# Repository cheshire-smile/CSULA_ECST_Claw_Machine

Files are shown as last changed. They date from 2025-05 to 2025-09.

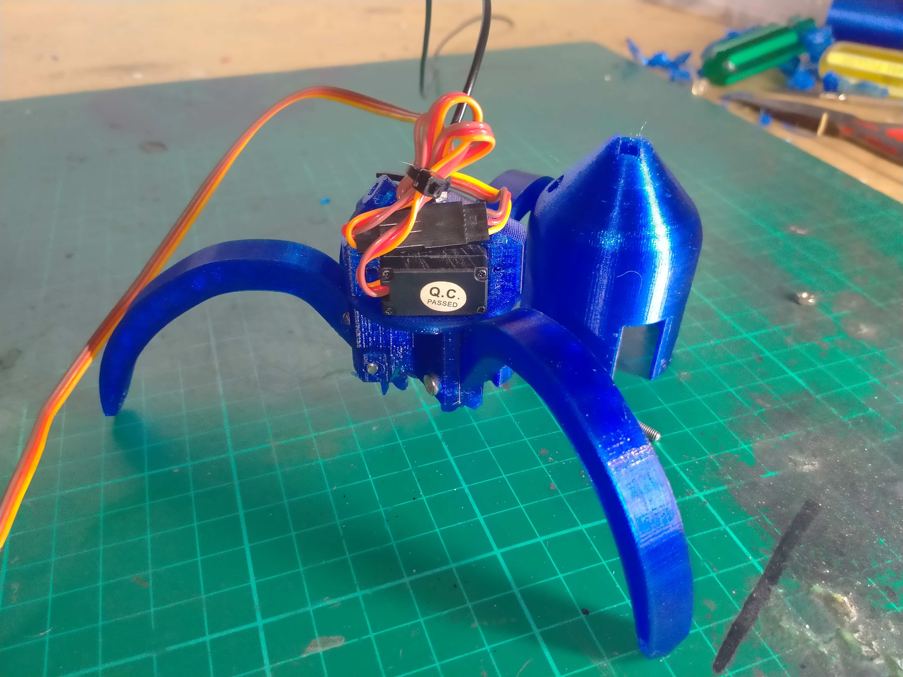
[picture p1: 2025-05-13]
Design_Files/Claw_Machine_V5/7_3 Cube Parts/Sub_Assemblys/Mini Servo operated Claw Machine Claw Grabber - 4826548/images/IMG20210413201654.jpeg

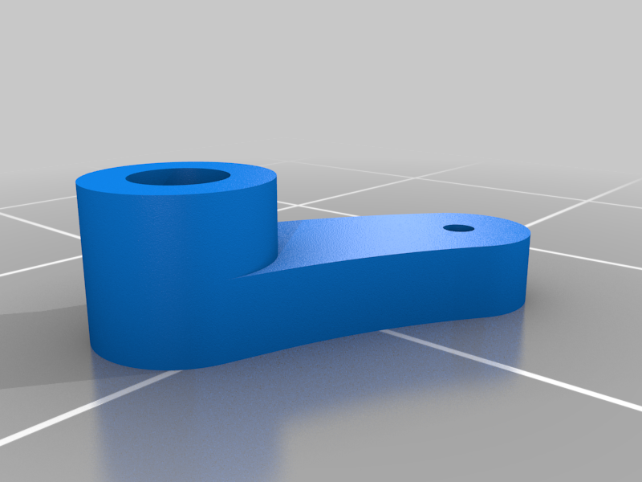
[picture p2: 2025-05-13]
Design_Files/Claw_Machine_V5/7_3 Cube Parts/Sub_Assemblys/Mini Servo operated Claw Machine Claw Grabber - 4826548/images/Servo_Linkage_Part_2.png

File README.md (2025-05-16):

This was a project created at California State University
as part of the SMART internship in Summer of 2024

It is a claw machine designed and built.
The design files contain the solidworks files used to CNC, laster cut, and 3D print the necessary parts

The code is designed for an STM32 NUCLEO-F030R8 board

CSULA ECST
https://www.calstatela.edu/ecst

information about the SMART internship:
https://www.smartscholarship.org/smart/en

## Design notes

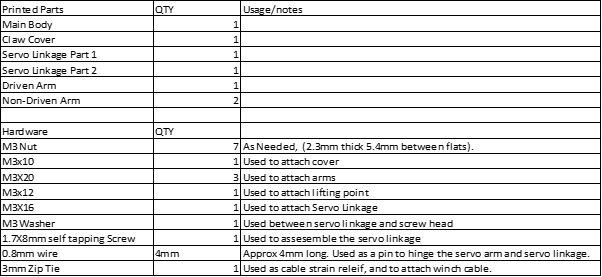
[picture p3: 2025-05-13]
Design_Files/Claw_Machine_V5/7_3 Cube Parts/Sub_Assemblys/Mini Servo operated Claw Machine Claw Grabber - 4826548/images/Hardware.png

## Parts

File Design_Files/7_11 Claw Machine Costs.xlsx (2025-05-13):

Received? | Item/Material | Amount Needed | Price | Total Cost | Notes | Link
FALSE |  |  |  | $440.57
FALSE | 24in Aluminum | 12 | $3.98 | $47.76 | Includes 2 for the Gantry that has NOT been added to Solidworks
FALSE | 36in Aluminum | 5 | $5.72 | $28.60
FALSE | 30in Aluminum | 2 | $4.85 | $9.70
TRUE | 25.5 x 22.35in Acyrlic (24 X 36 order) | 1 | $37.35 | $37.35 | For the front | https://www.mcmaster.com/8560K261/
TRUE | 25.5 x 22.44in Acrylic(24 X 36 order) | 2 | $37.35 | $74.70 | For the 2 sides | https://www.mcmaster.com/8560K261/
TRUE | Joystick | 1 | $12.18 | $12.18 |  | https://www.amazon.com/Machine-Fighting-Joystick-Compact-Lifespan/dp/B0C3ZKVRTC
TRUE | Button | 1 | $12.99 | $12.99 | For Drop, not sure if one in link works | https://www.amazon.com/EG-STARTS-American-Standard-Switchable/dp/B07GBSJX2H?rnid=386453011
TRUE | Idler Timing Pulley w/Bearing 20T | 1 | $9.99 | $9.99 | For CoreXY configuration Kit comes with 10 Pulleys | https://www.amazon.com/gp/product/B07J4JC2N7/ref=ox_sc_act_title_1?smid=AMFXXBA3KGILA&psc=1
TRUE | V Slot Gantry Plate | 2 | $7.67 | $15.34 | For X Axis motion | https://www.amazon.com/gp/product/B0986PYTNJ/ref=ox_sc_act_title_2?smid=A2DGLVBBDAJTOF&th=1
TRUE | GT2 Timing Belt and Pulley Kit | 1 | $14.99 | $14.99 | For X and Y motion, only comes with one belt | https://www.amazon.com/gp/product/B07XG9JN5B/ref=ox_sc_act_title_3?smid=AK64CGABQOWCO&th=1
TRUE | 2020 Profile X-axis Synchronous Belt Tensioner | 2 | $13.99 | $27.98 | For tensioning x and y axis belts | https://www.amazon.com/gp/product/B07XL41QNH/ref=ox_sc_act_title_4?smid=A3C0HXP4AGBIOG&th=1
TRUE | V Wheel with Plate and 6mm Belt Buckle | 1 | $18.99 | $18.99 | For antry payload (claw) | https://www.amazon.com/gp/product/B08M3JKKZY/ref=ox_sc_act_title_5?smid=A3C0HXP4AGBIOG&th=1
TRUE | Aluminum Extrusion Profiles Corner Brackets with T-Nuts | 1 | $19.97 | $19.97 | Kit Comes with 20 | https://www.amazon.com/gp/product/B0855V2JV3/ref=ox_sc_act_title_1?smid=A4HTD69KS4TBJ&th=1
TRUE | 2020 L Brackets | 1 | $11.97 | $11.97 | L Bracket for cross members | https://www.amazon.com/gp/product/B09BC1D3H2/ref=ox_sc_act_title_2?smid=A4HTD69KS4TBJ&psc=1
TRUE | GT2 Belt 2mm Pitch 6mm Wide | 1 | $9.99 | $9.99 | For Y axis | https://www.amazon.com/HICTOP-Printer-Creality-Printers-16-5ft/dp/B00YMM6IQW
TRUE | Stepper Motor | 2 | $21.95 | $43.90 | Motion | https://www.pololu.com/product/2267
FALSE | Stepper Motor Mounting Plate | 1 | $9.79 | $9.79 | Comes with 2 | https://www.amazon.com/HEVSTIL-Mounting-Aluminum-Suitable-Stepper/dp/B09XCD5F2Y
TRUE | Stepper Driver Board | 2 | $7.95 | $15.90 | Motion | https://www.pololu.com/product/2134
TRUE | Limit Switches | 1 | $5.99 | $5.99 | For Homing and safety | https://www.amazon.com/HiLetgo-KW12-3-Roller-Switch-Normally/dp/B07X142VGC
TRUE | STM32 Nucleo F401RE | 1 |  | $0.00 | Already on hand
TRUE | 5V Power Supply | 1 | $12.49 | $12.49 | 5v power supply | https://www.amazon.com/MEAN-WELL-RS-15-5-Supply-Single/dp/B005T6UJBU
 |  |  |  | $0.00
 |  |  |  | $0.00
 |  |  |  | $0.00
 |  |  |  | $0.00
 |  |  |  | $0.00
 |  |  |  | $0.00
 |  |  |  | $0.00
 |  |  |  | $0.00
 |  |  |  | $0.00
 |  |  |  | $0.00
 |  |  |  | $0.00

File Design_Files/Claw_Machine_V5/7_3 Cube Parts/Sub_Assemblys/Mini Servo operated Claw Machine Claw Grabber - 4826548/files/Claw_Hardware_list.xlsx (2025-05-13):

Printed Parts | QTY | Usage/notes
Main Body | 1
Claw Cover | 1
Servo Linkage Part 1 | 1
Servo Linkage Part 2 | 1
Driven Arm | 1
Non-Driven Arm | 2
Hardware | QTY
M3 Nut | 7 | As Needed, (2.3mm thick 5.4mm between flats).
M3x10 | 1 | Used to attach cover
M3X20 | 3 | Used to attach arms
M3x12 | 1 | Used to attach lifting point
M3X16 | 1 | Used to attach Servo Linkage
M3 Washer | 1 | Used between servo linkage and screw head
1.7X8mm self tapping Screw | 1 | Used to assesemble the servo linkage
0.8mm wire | 4mm | Approx 4mm long. Used as a pin to hinge the servo arm and servo linkage.
3mm Zip Tie | 1 | Used as cable strain releif, and to attach winch cable.

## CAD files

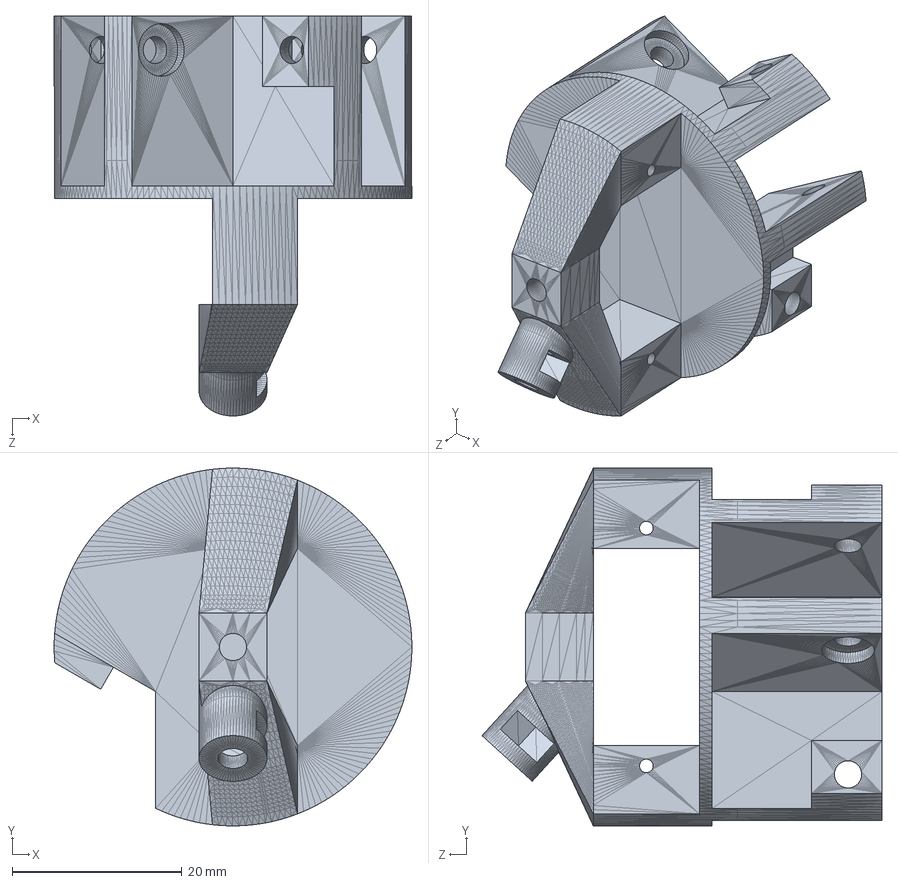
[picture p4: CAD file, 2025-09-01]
Design_Files/Claw_Machine_V5/7_3 Cube Parts/Sub_Assemblys/Mini Servo operated Claw Machine Claw Grabber - 4826548/files/main_body.SLDPRT
42.1 x 42.1 x 47.1 mm

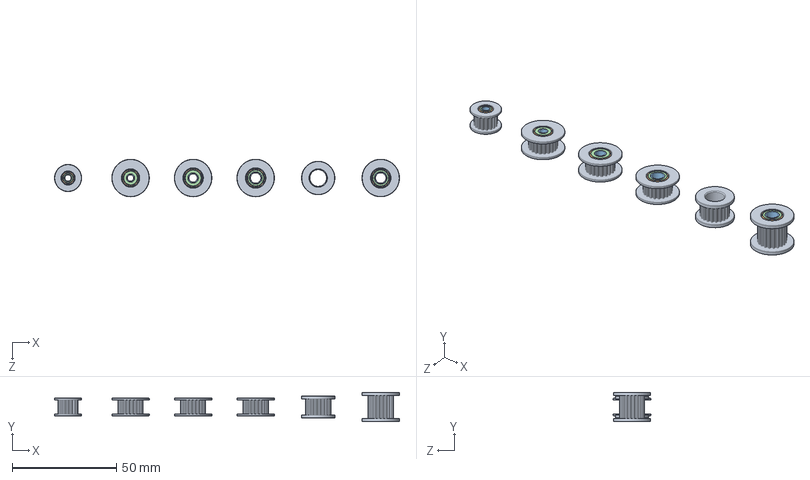
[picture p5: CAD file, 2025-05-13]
Design_Files/Alice - Claw_Machine_V3/7_3 Cube Parts/Sub_Assemblys/Corner_Idler_Pulley/Idler__Pulley/GT2 Timing Idler Pulley, Configurable, Pulleys Lined Up in Assembly.SLDASM
165.5 x 14.0 x 18.0 mm
Body, GT2 Timing Idler Pulley, Configurable x 6
Bearing Outer Ring, GT2 Timing Idler Pulley, Configurable x 10
Bearing Inner Ring, GT2 Timing Idler Pulley, Configurable x 10
Bearing Seal, GT2 Timing Idler Pulley, Configurable x 20
Bearing Ball, GT2 Timing Idler Pulley, Configurable x 98

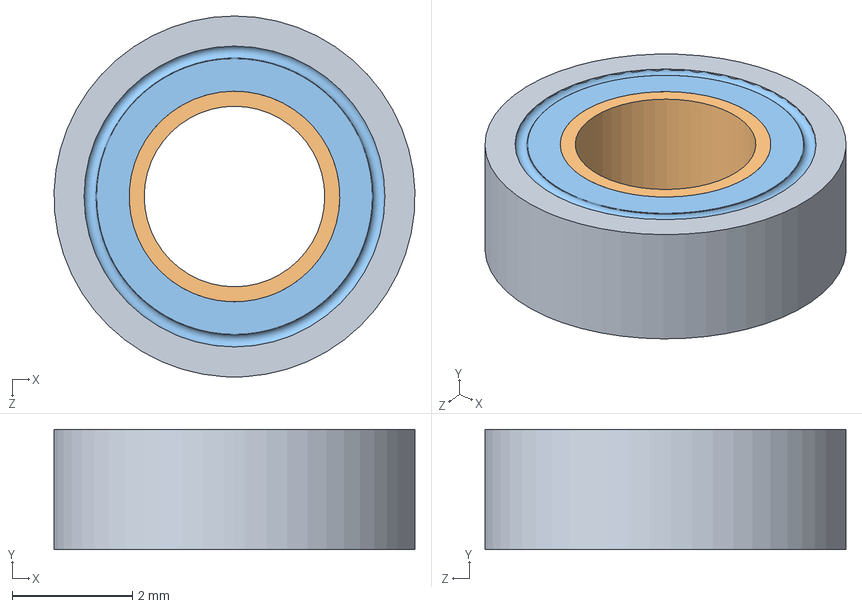
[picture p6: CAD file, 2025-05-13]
Design_Files/Alice - Claw_Machine_V3/7_3 Cube Parts/Sub_Assemblys/Corner_Idler_Pulley/Idler__Pulley/Bearing Subassy, GT2 Timing Idler Pulley, Configurable.SLDASM
6.00 x 2.00 x 6.00 mm
Bearing Outer Ring, GT2 Timing Idler Pulley, Configurable
Bearing Inner Ring, GT2 Timing Idler Pulley, Configurable
Bearing Seal, GT2 Timing Idler Pulley, Configurable
Bearing Ball, GT2 Timing Idler Pulley, Configurable

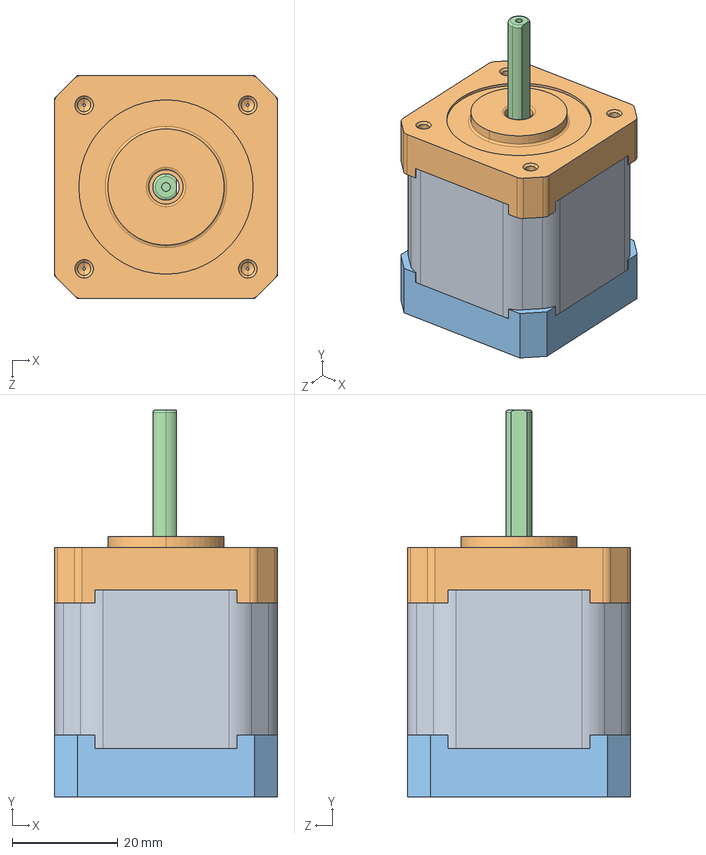
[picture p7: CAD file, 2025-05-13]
Design_Files/Alice - Claw_Machine_V3/7_3 Cube Parts/Sub_Assemblys/nema-17-stepper-motor/NEMA 17 Stepper Motor Assembly.STEP
42.3 x 73.3 x 42.3 mm
NEMA 17 Stepper Motor Middle
NEMA 17 Stepper Motor Top
NEMA 17 Stepper Motor Bottom
NEMA 17 Stepper Motor Shaft
pan cross head_am_B18.6.7M - M2.5 x 0.45 x 13 Type I Cross Recessed PHMS --13N x 4

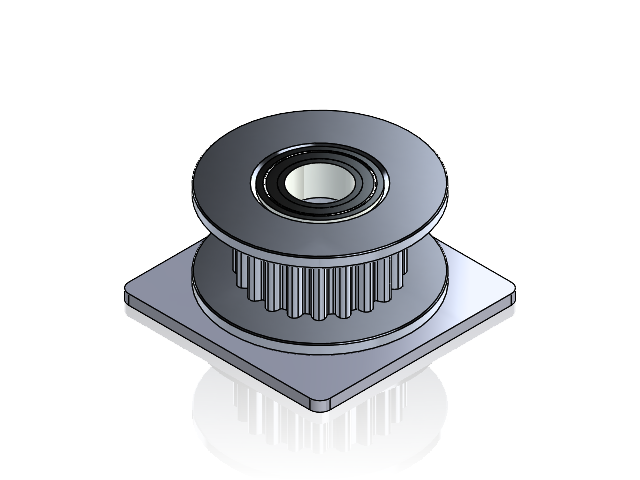
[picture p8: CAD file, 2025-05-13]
Design_Files/Alice - Claw_Machine_V3/7_3 Cube Parts/Sub_Assemblys/Corner_Idler_Pulley/Corner_Idler_Pulley.SLDASM
Corner_Idler_Pulley
Body, GT2 Timing Idler Pulley, Configurable
Bearing Outer Ring, GT2 Timing Idler Pulley, Configurable x 2
Bearing Inner Ring, GT2 Timing Idler Pulley, Configurable x 2
Bearing Seal, GT2 Timing Idler Pulley, Configurable x 4
Bearing Ball, GT2 Timing Idler Pulley, Configurable x 24

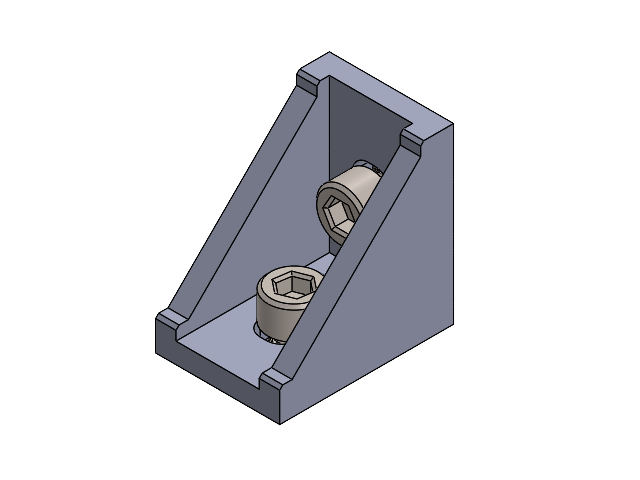
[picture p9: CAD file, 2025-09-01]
Design_Files/Claw_Machine_V5/7_3 Cube Parts/Sub_Assemblys/Corner_Bracket.SLDASM
Ke goc 28x28x20mm
M5x8 x 2
T NUT M5 2020S x 2

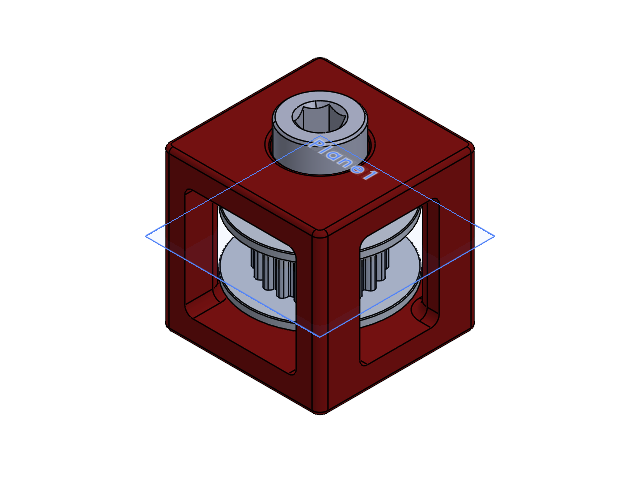
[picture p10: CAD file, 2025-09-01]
Design_Files/Claw_Machine_V5/7_3 Cube Parts/Sub_Assemblys/Corner_Idler_Pulley/Corner_Idler_Pulley.SLDASM
Corner_Idler_Pulley
Body, GT2 Timing Idler Pulley, Configurable
Bearing Outer Ring, GT2 Timing Idler Pulley, Configurable x 2
Bearing Inner Ring, GT2 Timing Idler Pulley, Configurable x 2
Bearing Seal, GT2 Timing Idler Pulley, Configurable x 4
Bearing Ball, GT2 Timing Idler Pulley, Configurable x 24
91290A252_Alloy Steel Socket Head Screw.step

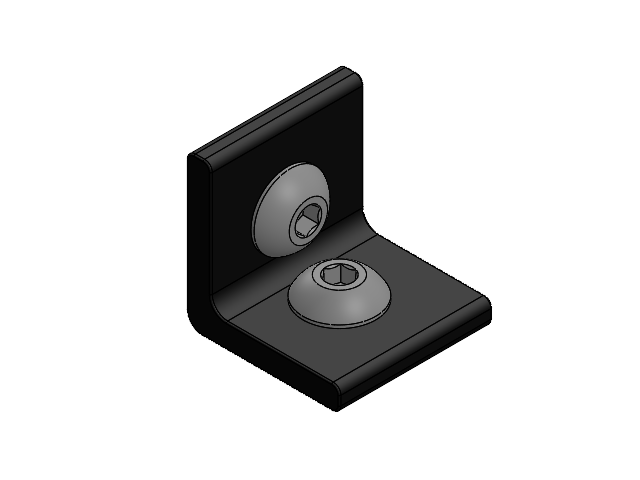
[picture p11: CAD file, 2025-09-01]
Design_Files/Claw_Machine_V5/7_3 Cube Parts/Sub_Assemblys/L_Bracket_Sub_Assembly.SLDASM
2020_L-Bracket_Black
T NUT M5 2020S x 2
91239A222_Button Head Hex Drive Screw x 2

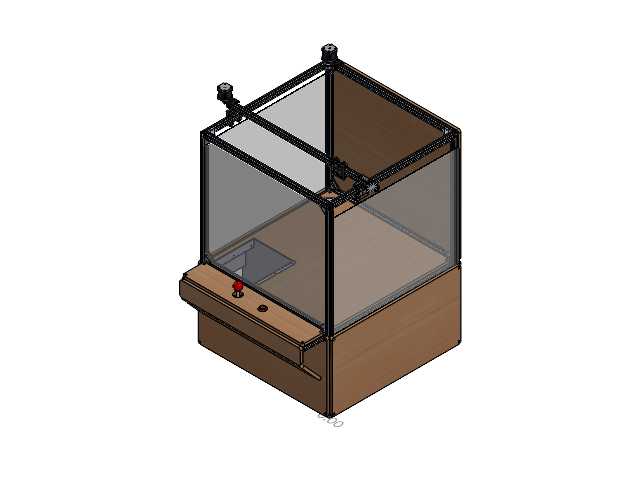
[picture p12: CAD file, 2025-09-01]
Design_Files/Claw_Machine_V5/7_3 Cube.SLDASM
36inaluminum x 4
24inaluminum x 10
30inaluminum x 2
25.5inx13.52insidebottomwoodhole
25.5inx13.57inbackbottomwood
24.08inx23.92ininsidewood
25.5inx25.5inultbottomwood
25.5inx22.44insideacyrlic x 2
25.5inx22.35infrontacyrlic
25.5inx22.35inbackwood
25.5inx13.52incutsidebottomwood
25.5inx13.57infrontbottomwoodhole
23.92inx4.43infrontwoodforjoystick
pins_1.step
button_mechanics-0_1.step
shell_body_1.step
nut_1.step
button_body_1.step
led_pins_1.step
Connector 5P_1.step
JLF-P1 Mounting Plate_1.step
Sanwa LB-35 Balltop Dark Red_1.step
Sanwa JL-S9F Shaft_1.step
Solo Sanwa JLF Dustwasher_1.step
Sanwa LB-30 N-S Battop Adapter_1.step
Sanwa JLF P-2 Main Body_1.step
Sanwa JLF-P-4 Pivot_1.step
Push Button Arcade_1.step
Push Button Arcade_clne150_1.step
Push Button Arcade_clne151_1.step
Push Button Arcade_clne152_1.step
Sanwa JLF Actuator_1.step
Circlip_1.step
Sanwa JLF-P-6 Pressure Spring Base_1.step
Sanwa TP-MA PCB_1.step
Sanwa JLF-MW Washer_1.step
Sanwa JLF Spring_1.step
Sanwa GT-8F 16-Way Restrictor Plate_1.step
M3x10-Screw_1.step
M3x10-Screw001_1.step
M3x10-Screw002_1.step
M3x10-Screw003_1.step
M3-Nut_1.step
M3-Nut004_1.step
M3-Nut007_1.step
M3-Nut006_1.step
Sanwa GT Restrictor Plate_1.step
T NUT M5 2020S x 47
Ke goc 28x28x20mm x 20
M5x8 x 39
695mmaluminum
ST-M11 x 2
NEMA 17 Stepper Motor Middle x 2
NEMA 17 Stepper Motor Top x 2
NEMA 17 Stepper Motor Bottom x 2
NEMA 17 Stepper Motor Shaft x 2
pan cross head_am x 8
Pulley_GT2_20T_b5 x 2
2020 Tensioner Pulley Cradle
2020 Tensioner Rear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

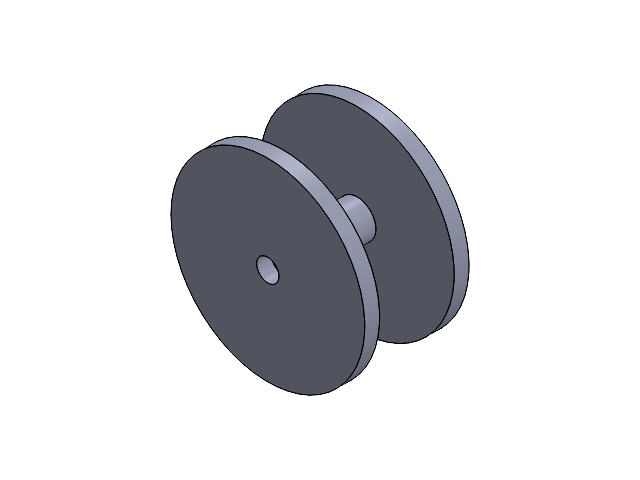
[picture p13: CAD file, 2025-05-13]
Design_Files/Alice - Claw_Machine_V3/7_3 Cube Parts/Winch/Spool.SLDASM
Middle part 5mm
Outer part 26mm x 2

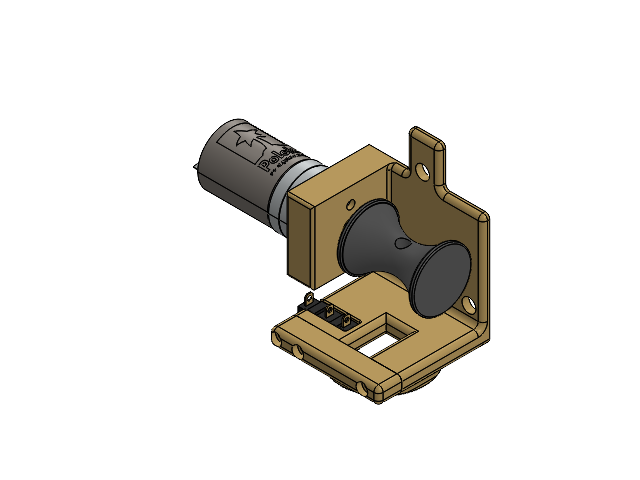
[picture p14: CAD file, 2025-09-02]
Design_Files/Claw_Machine_V5/7_3 Cube Parts/Sub_Assemblys/Winch/Gantry_Plate_with_limit.SLDASM
Gantry_Plate
NO-NC Bump Switch.step
25d-metal-gearmotor-34-47
Crane_Spool_forCNC

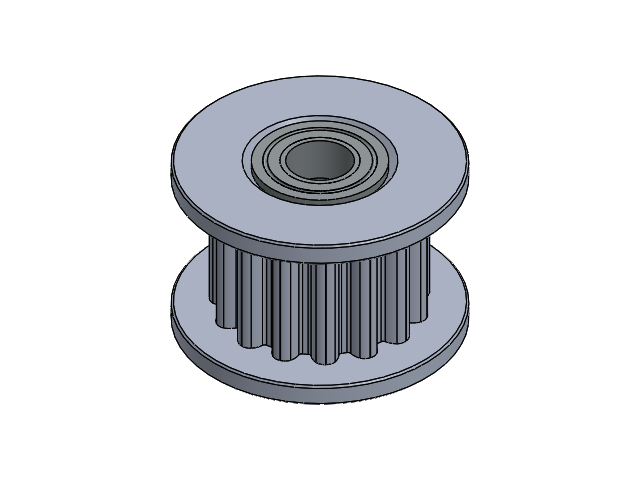
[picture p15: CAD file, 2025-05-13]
Design_Files/Alice - Claw_Machine_V3/7_3 Cube Parts/Sub_Assemblys/Corner_Idler_Pulley/Idler__Pulley/GT2 Timing Idler Pulley, Configurable.SLDASM
Body, GT2 Timing Idler Pulley, Configurable
Bearing Outer Ring, GT2 Timing Idler Pulley, Configurable x 2
Bearing Inner Ring, GT2 Timing Idler Pulley, Configurable x 2
Bearing Seal, GT2 Timing Idler Pulley, Configurable x 4
Bearing Ball, GT2 Timing Idler Pulley, Configurable x 24

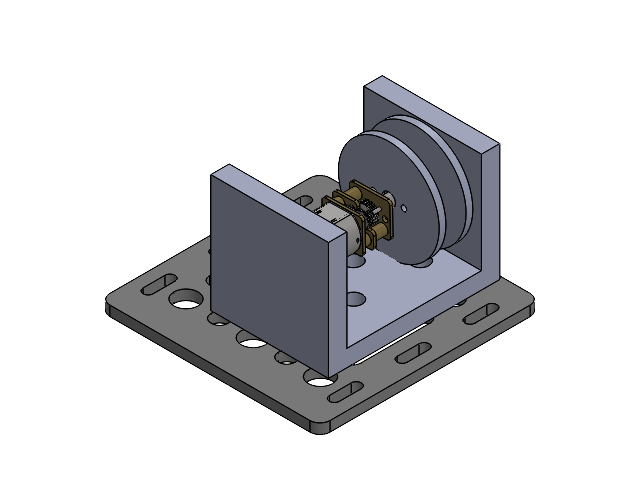
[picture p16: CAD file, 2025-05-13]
Design_Files/Alice - Claw_Machine_V3/7_3 Cube Parts/Winch/3D model assembly.SLDASM
Updated Spool
Engrenagem reta1.stp
Engrenagem reta2.stp
Engrenagem reta1_1.stp
Engrenagem reta2_1.stp
Engrenagem reta1_2.stp
Engrenagem reta2_2.stp
Engrenagem reta1_3.stp
Engrenagem reta2_3.stp
Engrenagem reta1_4.stp
Engrenagem reta2_4.stp
Base.stp
Rotor.stp
Apoio Contato.stp
Contato.stp
Suporte Contato.stp
Im_X_E3s.stp
Terminais.stp x 2
Escovas.stp
Chapa Inferior.stp
Chapa Intermedi_X_E1ria.stp
Chapa Superior.stp
Eixo Maior - Engrenagem.stp
Eixo Menor - Engrenagem.stp
Parafuso.stp x 2
Suporte Bobinas.stp
Eixo Menor - Engrenagem_1.stp
Eixo - Encaixe D.stp
Carca_X_E7a.stp
V-Slot Gantry Plate 20mm.step
Connecting Piece

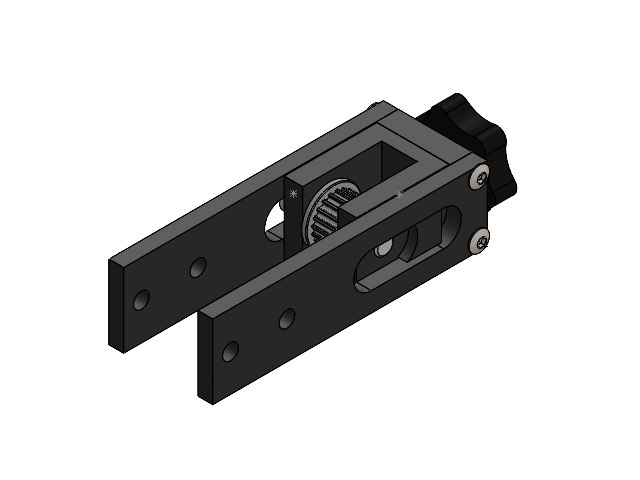
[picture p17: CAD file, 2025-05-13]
Design_Files/Alice - Claw_Machine_V3/7_3 Cube Parts/Sub_Assemblys/2020-extrusion-gt2-belt-tensioner/2020 Belt Tensioner G_K_Long.SLDASM
2020 Tensioner Pulley Cradle
2020 Tensioner Rear
2020 Tensioner Long side x 2
2020 Tensioner Adjusting Screw
M5 Cap head Screw
GT2_Idler_20T.step
Ball bearing (5x9x3)mm003.step
Ball bearing (5x9x3)mm004.step
M3x10mm bolt x 4

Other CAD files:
Design_Files/Claw_Machine_V5/7_3 Cube Parts/joystick and button/button_mechanics_1.step.SLDASM
Design_Files/Alice - Claw_Machine_V3/7_3 Cube Parts/joystick and button/button_mechanics_1.step.SLDASM
Design_Files/Claw_Machine_V5/7_3 Cube Parts/Sub_Assemblys/Corner_Idler_Pulley/Idler__Pulley/GT2 Timing Idler Pulley, Configurable.SLDASM
Design_Files/Alice - Claw_Machine_V3/7_3 Cube Parts/Winch/Combined part.SLDASM
Design_Files/2020_L-Bracket_Black - Copy.SLDPRT
Design_Files/Alice - Claw_Machine_V3/7_3 Cube Parts/Corner_Idler_Pulley.SLDPRT
Design_Files/Alice - Claw_Machine_V3/7_3 Cube Parts/Ke goc 28x28x20mm.SLDPRT
Design_Files/Alice - Claw_Machine_V3/7_3 Cube Parts/Microprocessor Cover.SLDPRT
Design_Files/Alice - Claw_Machine_V3/7_3 Cube Parts/Pulley_GT2_20T_b5.SLDPRT
Design_Files/Alice - Claw_Machine_V3/7_3 Cube Parts/ST-M11.STEP
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

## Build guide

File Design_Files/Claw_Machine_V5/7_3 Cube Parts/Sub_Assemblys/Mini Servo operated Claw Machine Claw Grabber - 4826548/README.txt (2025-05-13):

Mini Servo operated Claw Machine Claw Grabber by David97 on Thingiverse: https://www.thingiverse.com/thing:4826548

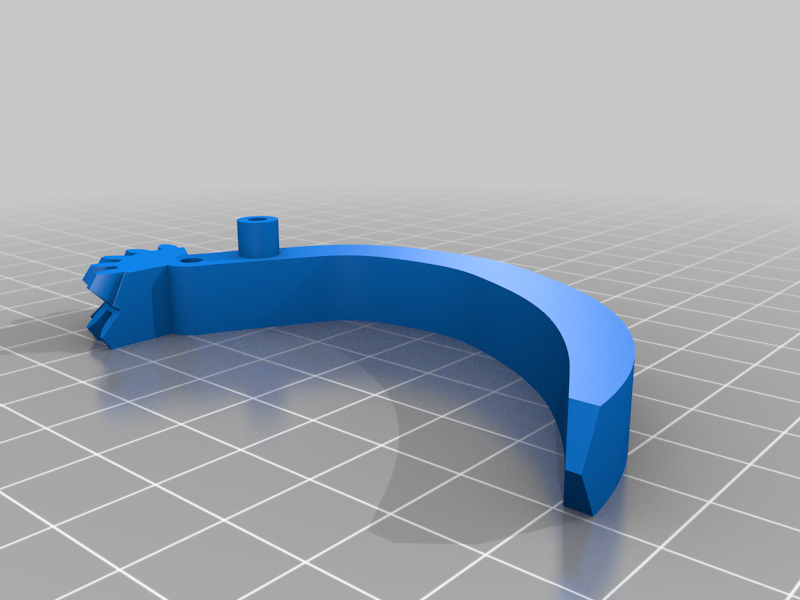
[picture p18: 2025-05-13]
Design_Files/Claw_Machine_V5/7_3 Cube Parts/Sub_Assemblys/Mini Servo operated Claw Machine Claw Grabber - 4826548/images/Driven_Arm.png

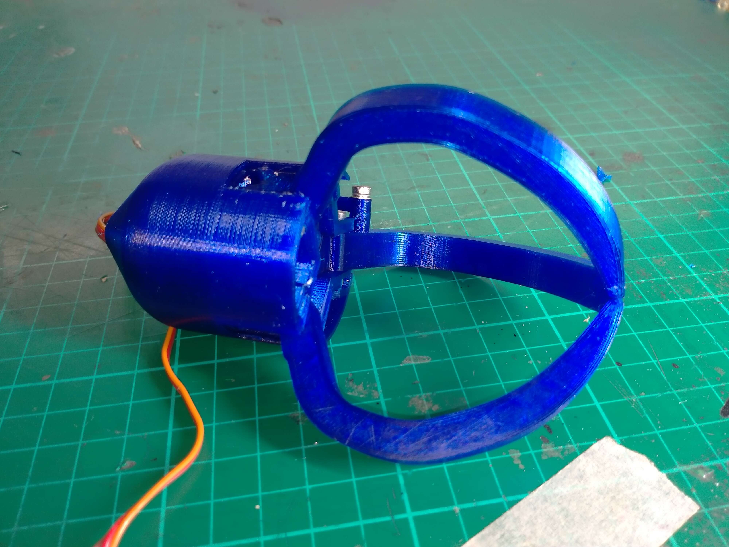
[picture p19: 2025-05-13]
Design_Files/Claw_Machine_V5/7_3 Cube Parts/Sub_Assemblys/Mini Servo operated Claw Machine Claw Grabber - 4826548/images/IMG20210413193744.jpeg

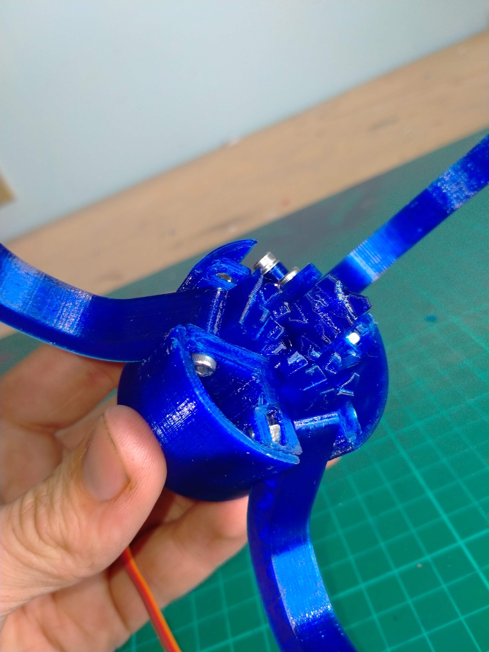
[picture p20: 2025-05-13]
Design_Files/Claw_Machine_V5/7_3 Cube Parts/Sub_Assemblys/Mini Servo operated Claw Machine Claw Grabber - 4826548/images/IMG20210413193801.jpeg

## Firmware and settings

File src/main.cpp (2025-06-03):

//This code was created as part of the SMART internship at CSULA ECST maker space Summer of 2024
//Author: Cosme A. Lavalle


#include <Arduino.h>
#include <DRV8834.h>
#include <Servo.h>
#include "MultiDriver.h"
#include "SyncDriver.h"
#include <STM32FreeRTOS.h>
#include <task.h>


// Define pin connections for Nucleo-64 F401RE
#define X_STEP_PIN          D6
#define X_DIR_PIN           D5
#define X_SLEEP_PIN         D13
#define Y_STEP_PIN          D9
#define Y_DIR_PIN           D8
#define Y_SLEEP_PIN         D13

#define WINCH_IN1           PB13 // define motor pin numbers
#define WINCH_IN2           PB14
#define CLAW_PWM_PIN        PC6
#define LIMIT_X1            PB15
#define LIMIT_X2            PB1
#define LIMIT_Y1            PB2
#define LIMIT_Y2            PB12
#define LIMIT_WINCH         PC5

#define JOYSTICK_UP_PIN     D2
#define JOYSTICK_DOWN_PIN   D3
#define JOYSTICK_LEFT_PIN   D10
#define JOYSTICK_RIGHT_PIN  D11
#define DROP_BUTTON_PIN     D12

#define MICROSTEPS  1
#define MOTOR_STEPS 200
#define MOTOR_RPM   600

#define WINCH_SPEED 150
#define WINCH_DROP_TIME 1500

#define RIGGING_VALUE 5 //0 to 10, the higher the number the more rigged the claw is. 

bool error=false; //Global error state, if this is true, all other task are shut down until ou reboot.
const long limit_X1_timeout = 5000; //If the Limit swith isn't activated in this amount of time, the machine will enter error state.
const long limit_X2_timeout = 5000;
const long limit_Y1_timeout = 5000;
const long limit_Y2_timeout = 5000;
long limit_Winch_timeout = WINCH_DROP_TIME+2000;

DRV8834 stepperX(MOTOR_STEPS, X_DIR_PIN, X_STEP_PIN);
DRV8834 stepperY(MOTOR_STEPS, Y_DIR_PIN, Y_STEP_PIN);
SyncDriver controller(stepperX, stepperY);


Servo myservo;

TaskHandle_t TaskHandleJoystick;
TaskHandle_t TaskHandleDropButton;
TaskHandle_t TaskHandleError;

bool dropActivated = false;
typedef enum STATES {
    S_IDLE,
    S_OPEN,
    S_CLOSE,
    S_TEST,
    S_RIGGED

} STATES;

STATES clawState = S_OPEN;

//fuctions
void setupPins();
void bootUpSequence();
void dropSequence();
void homeGantry();
void chuteGantry();
void homeWinch();
void claw(STATES state);
//tasks
void TaskJoystick(void *pvParameters);
void TaskDropButton(void *pvParameters);
void TaskError(void *pvParameters);


void setup() {
    Serial.begin(115200);
    setupPins();
    stepperX.begin(MOTOR_RPM, MICROSTEPS);
    stepperY.begin(MOTOR_RPM, MICROSTEPS);
    myservo.attach(CLAW_PWM_PIN);

    xTaskCreate(
        TaskJoystick,     // Task function
        "JoystickTask",   // Name of task
        1000,             // Stack size (bytes)
        NULL,             // Parameter to pass
        2,                // Task priority
        &TaskHandleJoystick // Task handle
    );

    xTaskCreate(
        TaskDropButton,   // Task function
        "DropButtonTask", // Name of task
        1000,             // Stack size (bytes)
        NULL,             // Parameter to pass
        1,                // Task priority
        &TaskHandleDropButton // Task handle
    );

        xTaskCreate(
        TaskError,   // Task function
        "ErrorTask", // Name of task
        1000,             // Stack size (bytes)
        NULL,             // Parameter to pass
        3,                // Task priority
        &TaskHandleError // Task handle
    );

    vTaskStartScheduler();
}

void loop() {
    // Nothing here, as tasks are managed by FreeRTOS
}

//--------------Tasks---------------


// Task to handle joystick input and move steppers
void TaskJoystick(void *pvParameters) {
    
    bootUpSequence();
    unsigned long previousMillis = 0;  // Stores last time the position was printed
    const long interval = 10000;  // Interval for position output (1000 ms = 1 second

    for (;;) {
        bool xMotorActive = false;
        bool yMotorActive = false;
        int xSteps = 50;
        int ySteps = 50;
        bool upState = 1;
        bool downState = 1;
        bool leftState = 1;
        bool rightState= 1;
        bool x1LimitState=1;
        bool x2LimitState=1;
        bool y1LimitState=1;
        bool y2LimitState=1;
        bool winchLimitState=1;

        //read the joystick and limit switches
        upState=digitalRead(JOYSTICK_UP_PIN);
        downState=digitalRead(JOYSTICK_DOWN_PIN);
        leftState=digitalRead(JOYSTICK_LEFT_PIN);
        rightState=digitalRead(JOYSTICK_RIGHT_PIN);
        x1LimitState=(digitalRead(LIMIT_X1));
        x2LimitState=(digitalRead(LIMIT_X2));
        y1LimitState=(digitalRead(LIMIT_Y1));
        y2LimitState=(digitalRead(LIMIT_Y2));
        winchLimitState=(digitalRead(LIMIT_WINCH));

        unsigned long currentMillis = millis();

        // Print joystick and limit states every 10 seconds for debugging
        if (currentMillis - previousMillis >= interval) {

            Serial.print("Up: ");
            Serial.print(upState);
            Serial.print("           Down: ");
            Serial.print(downState);
            Serial.print("           Left: ");
            Serial.print(leftState);
            Serial.print("          Right: ");
            Serial.println(rightState);
            Serial.print("Y Limit rear: ");
            Serial.print(y1LimitState);
            Serial.print(" Y limit front: ");
            Serial.print(y2LimitState);
            Serial.print(" X Limit Left: ");
            Serial.print(x1LimitState);
            Serial.print(" X limit right: ");
            Serial.print(x2LimitState);
            Serial.print(" Winch Limit: ");
            Serial.println(winchLimitState);

            previousMillis = currentMillis;

        }

        //if nobody is playing with the machine, put the motors to sleep.
        if(upState&&downState&&leftState&&rightState==1&&dropActivated==false){
            digitalWrite(X_SLEEP_PIN, LOW);
        } else {

            //figure out which way to spin the motors
            if(downState==0) ySteps=ySteps*-1;
            if(rightState==0) xSteps=xSteps*-1;
            if(downState&&upState) ySteps=0;
            if(leftState&&rightState) xSteps=0;

            //Check the limit switches and direction
            if(upState&&y2LimitState==0)    {ySteps=0;}
            if(downState&&y1LimitState==0)  {ySteps=-0;}
            if(leftState&&x2LimitState==0)  {xSteps=0;}
            if(rightState&&x1LimitState==0) {xSteps=-0;}

            //Move the motor if the drop sequence isn't active
            if (!dropActivated) {
                digitalWrite(X_SLEEP_PIN, HIGH);
                controller.move(xSteps, ySteps);
            }
        }

        vTaskDelay(pdMS_TO_TICKS(1)); // Small delay to debounce switches
    }
}

// Task to handle the drop button
void TaskDropButton(void *pvParameters) {
    //Test the claw on boot up
    claw(clawState=S_TEST);

    int speed = 255;

    for (;;) {
        if (digitalRead(DROP_BUTTON_PIN) == LOW) {

            dropSequence();
        }
        vTaskDelay(pdMS_TO_TICKS(10)); // Small delay to debounce switches
        
    }
}

// Task to handle Errors
void TaskError(void *pvParameters) {
    for (;;) {
        if (error==true) {
            Serial.println("!!!!!!!!!!!!!Error State detected suspending all tasks!!!!!!!!!!!!");
            Serial.println("!!!!!Reboot required to clear error!!!!!!!!");
            vTaskSuspendAll();
        }
        vTaskDelay(pdMS_TO_TICKS(100)); // Small delay to debounce switches
        
    }
}



//--------------Functions---------------
// Function to initialize pins
void setupPins() {
    pinMode(X_SLEEP_PIN, OUTPUT);
    pinMode(Y_SLEEP_PIN, OUTPUT);
    pinMode(CLAW_PWM_PIN, OUTPUT);

    pinMode(JOYSTICK_UP_PIN, INPUT_PULLUP);
    pinMode(JOYSTICK_DOWN_PIN, INPUT_PULLUP);
    pinMode(JOYSTICK_LEFT_PIN, INPUT_PULLUP);
    pinMode(JOYSTICK_RIGHT_PIN, INPUT_PULLUP);
    pinMode(DROP_BUTTON_PIN, INPUT_PULLUP);
    pinMode(LIMIT_X1, INPUT_PULLUP);
    pinMode(LIMIT_X2, INPUT_PULLUP);
    pinMode(LIMIT_Y1, INPUT_PULLUP);
    pinMode(LIMIT_Y2, INPUT_PULLUP);
    pinMode(LIMIT_WINCH, INPUT_PULLUP);

    digitalWrite(X_SLEEP_PIN, LOW);
    digitalWrite(Y_SLEEP_PIN, LOW);
}

// Boot-up sequence function
void bootUpSequence() {

    //change the winch timout to 10s just for bootup because spool might be completely unwound
    long held_value=limit_Winch_timeout;
    limit_Winch_timeout=10000;

    homeWinch();

    //put the winch timout limit back;
    limit_Winch_timeout=held_value;

    homeGantry();
    claw(clawState=S_OPEN);
}

void dropSequence() {

    dropActivated = true;

    //lower the winch
    analogWrite(WINCH_IN1, 0);
    analogWrite(WINCH_IN2, 0);
    analogWrite(WINCH_IN1, 255);
    vTaskDelay(pdMS_TO_TICKS(500));
    analogWrite(WINCH_IN1, WINCH_SPEED);
    vTaskDelay(pdMS_TO_TICKS(WINCH_DROP_TIME));
    analogWrite(WINCH_IN1, 0);

    vTaskDelay(pdMS_TO_TICKS(1000)); // Wait before next step

    //Close the claw
    bool rigged=(random(11)<(RIGGING_VALUE)) ? true : false; // are we rigging the claw this time?
    if (rigged) claw(clawState=S_RIGGED);
    else claw(clawState=S_CLOSE);
    vTaskDelay(pdMS_TO_TICKS(1000)); // Wait before next step


    //raise the winch
    homeWinch();
    vTaskDelay(pdMS_TO_TICKS(1000)); // Wait before next step


    //move the gantry to the chute
    chuteGantry();
    vTaskDelay(pdMS_TO_TICKS(2000)); // Wait before next step
    

    //open the claw
    claw(clawState=S_OPEN);
    vTaskDelay(pdMS_TO_TICKS(3000)); // Wait before next step


    //Return to home position
    homeGantry();


    vTaskDelay(pdMS_TO_TICKS(3000));// wait before starting again.

    dropActivated = false;
}


void homeGantry() {

    // Wake up motors
    digitalWrite(X_SLEEP_PIN, HIGH);
    digitalWrite(Y_SLEEP_PIN, HIGH);

    //start the clock for error timer
    unsigned long start_time = millis();
    unsigned long current_time = start_time;

    // Move to the left x limit
    while (digitalRead(LIMIT_X1)){

        if (current_time - start_time >= limit_X1_timeout) {
            Serial.println("!!!!!Error X1 limit switch timout!!!!!!!!");
            Serial.print(current_time);
            Serial.print("-");
            Serial.print(start_time);
            Serial.print("=");
            Serial.println(current_time-start_time);
            Serial.print("Limit is: ");
            Serial.println(limit_X1_timeout);
            error=true;
            break;
        }
        current_time=millis();
        stepperX.move(MOTOR_STEPS/4);
    }

    //Reset the error timer
    start_time = millis();
    current_time = start_time; 

    // Move to the back y limit
    while (digitalRead(LIMIT_Y1)) {

        if (current_time - start_time >= limit_Y1_timeout) {
            Serial.println("!!!!!Error Y1 limit switch timout!!!!!!!!");
            Serial.print(current_time);
            Serial.print("-");
            Serial.print(start_time);
            Serial.print("=");
            Serial.println(current_time-start_time);
            Serial.print("Limit is: ");
            Serial.println(limit_Y1_timeout);
            error=true;
            break;
        }
        current_time=millis();
        stepperY.move(MOTOR_STEPS/4);
    }

    // Put motors to sleep
    digitalWrite(X_SLEEP_PIN, LOW);
    digitalWrite(Y_SLEEP_PIN, LOW);
}

void homeWinch(){

    unsigned long start_time = millis();
    unsigned long current_time = start_time;  // Stores last time the position was printed

    //raise the winch until it hit's the limit switch
    analogWrite(WINCH_IN1, 0);
    analogWrite(WINCH_IN2, 0);

    //Raise the claw until it hits the limit switch

    if(digitalRead(LIMIT_WINCH)==1){
        analogWrite(WINCH_IN2, WINCH_SPEED);
    }

    while (digitalRead(LIMIT_WINCH))
    {
            
        if (current_time - start_time >= limit_Winch_timeout) {

            Serial.println("!!!!!Error Winch limit switch timout!!!!!!!!");
            Serial.print(current_time);
            Serial.print("-");
            Serial.print(start_time);
            Serial.print("=");
            Serial.println(current_time-start_time);
            Serial.print("Limit is: ");
            Serial.println(limit_Winch_timeout);
            error=true;
            break;
        }
        current_time=millis();
        delay(100);

    }

    analogWrite(WINCH_IN1, 0);
    analogWrite(WINCH_IN2, 0);

}

void chuteGantry() {
    // Wake up motors
    digitalWrite(X_SLEEP_PIN, HIGH);
    digitalWrite(Y_SLEEP_PIN, HIGH);

    // Move to the left x limit
    while (digitalRead(LIMIT_X1)){
        stepperX.move(MOTOR_STEPS/4);
    }
    // Move to the front y limit
    while (digitalRead(LIMIT_Y2)) {
        stepperY.move(MOTOR_STEPS/-4);
    }

    // Put motors to sleep
    digitalWrite(X_SLEEP_PIN, LOW);
    digitalWrite(Y_SLEEP_PIN, LOW);

}


void claw(STATES state){
    switch (state)
    {
    case S_OPEN:
        myservo.write(10);
        break;
    case S_CLOSE:
        myservo.write(90);
        break;
    case S_TEST:
        myservo.write(10);
        vTaskDelay(pdMS_TO_TICKS(1000));
        myservo.write(90);
        vTaskDelay(pdMS_TO_TICKS(1000));
        myservo.write(10);
        vTaskDelay(pdMS_TO_TICKS(1000));
        myservo.write(90);
        vTaskDelay(pdMS_TO_TICKS(1000));
        myservo.write(10);
        break;
    case S_RIGGED:
        myservo.write(70);
        break;    
    default:
        break;
    }
}

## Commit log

2025-05-13 Solidworks Files
    Adding Solidworks design files
    [2020 Belt Tensioner G_K.SLDASM, 2020 Belt Tensioner G_K.STEP, 2020 Belt Tensioner G_K_Long.SLDASM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]
2025-05-16 Winch update
    Started Modifying the Winch to add a sensor, specifically a limit switch.
    [Gantry_Plate.SLDPRT, Gantry_Plate_with_limit.SLDASM, NO-NC Bump Switch.SLDPRT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]
2025-05-16 Gantry plate refinements
    This is the first edition of the gantry plate with the limit switch. I'm gong to print it and hopefully it works on the first prototype.
    [Gantry_Plate.SLDPRT, Gantry_Plate_with_limit.SLDASM]
2025-05-17 Bug Fix, Stepper motors were bugun twice, might be why the stepper direction would randomly change.
    [main.cpp]
2025-06-03 Adding Error check for X&Y homing sequence.
    [main.cpp]
2025-08-29 Updated the Gantry plate
    The gantry plate had a problem with the stopper rolling over the edge and not triggering the limit switch. Updated the plate to solve the problem.
    [Gantry_Plate.SLDPRT, Gantry_Plate_with_limit.SLDASM]
2025-09-01 Files updated to Solidworks 2024
    Files updated to Solidworks 2024, also updated winch assembly and organized some files.
    [2020 Belt Tensioner G_K.SLDASM, 2020 Tensioner Adjusting Screw.SLDPRT, 2020 Tensioner Long side.SLDPRT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]
2025-09-02 Updated spppol for 3d printing
    [Crane_Spool_forCNC.SLDPRT, Gantry_Plate.SLDPRT, Gantry_Plate_with_limit.SLDASM]
